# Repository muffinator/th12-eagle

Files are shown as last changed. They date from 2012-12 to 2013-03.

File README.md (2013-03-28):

CAD and Docs for the TH12 sensor
================================

TH12 layout

[Schematic PDF](https://raw.github.com/malvira/th12-eagle/master/docs/th12-revD.pdf)

Tag-Connet Header
-----------------

### Pinout

tag-connect-pinout

Firmware
--------

[Open source firmware](https://github.com/malvira/th-12)

Datasheets
----------
[NCP1400](http://www.onsemi.com/pub_link/Collateral/NCP1400A-D.PDF)[digikey](http://www.digikey.com/product-detail/en/NCP1400ASN33T1G/NCP1400ASN33T1GOSCT-ND/2121294)

License
-------

The TH12 designs are owned by Redwire Consulting, LLC and relased
under the [CERN OPEN HARDWARE LICENCE v1.1](LICENSE.txt)

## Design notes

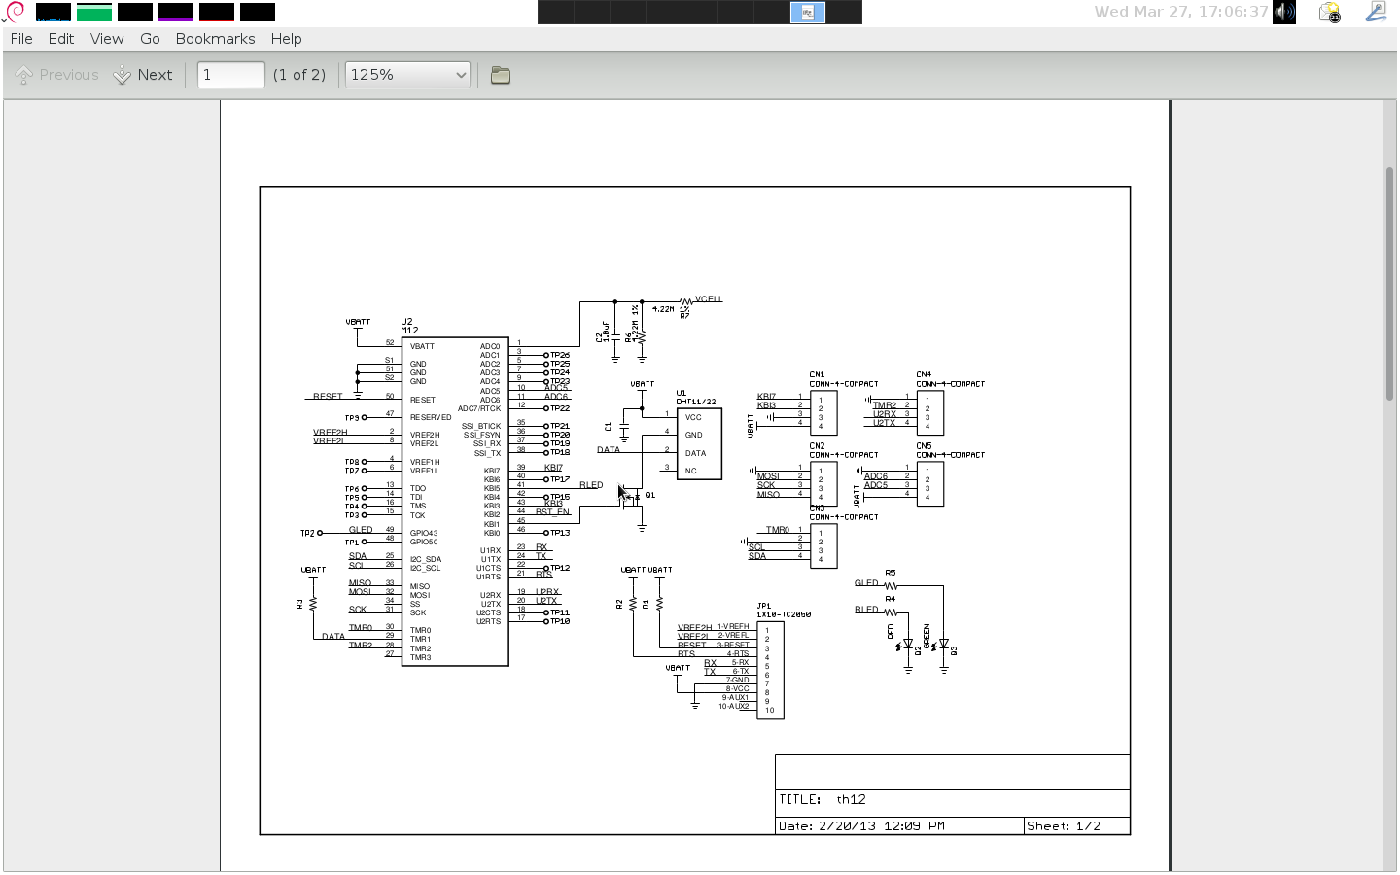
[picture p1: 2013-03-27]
docs/th12-schematic-thumb.png

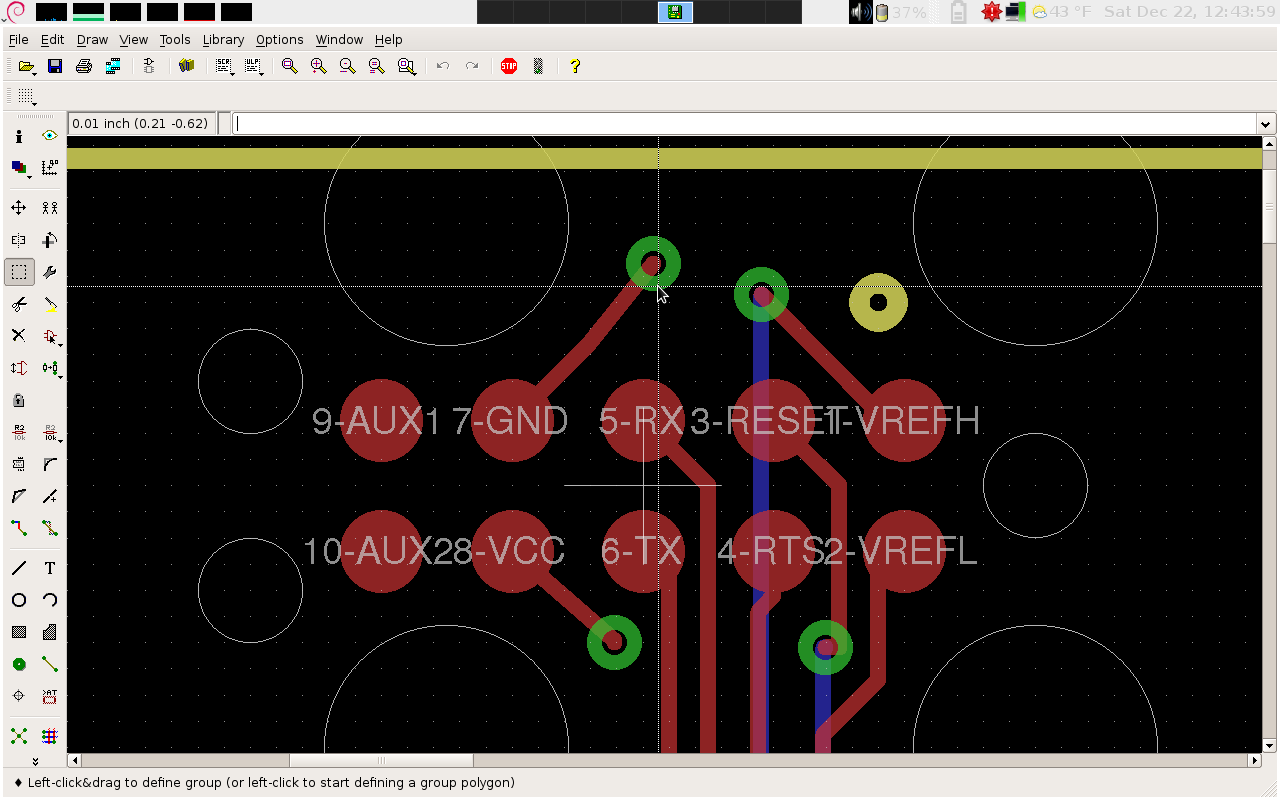
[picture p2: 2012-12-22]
docs/tc-pinout.png

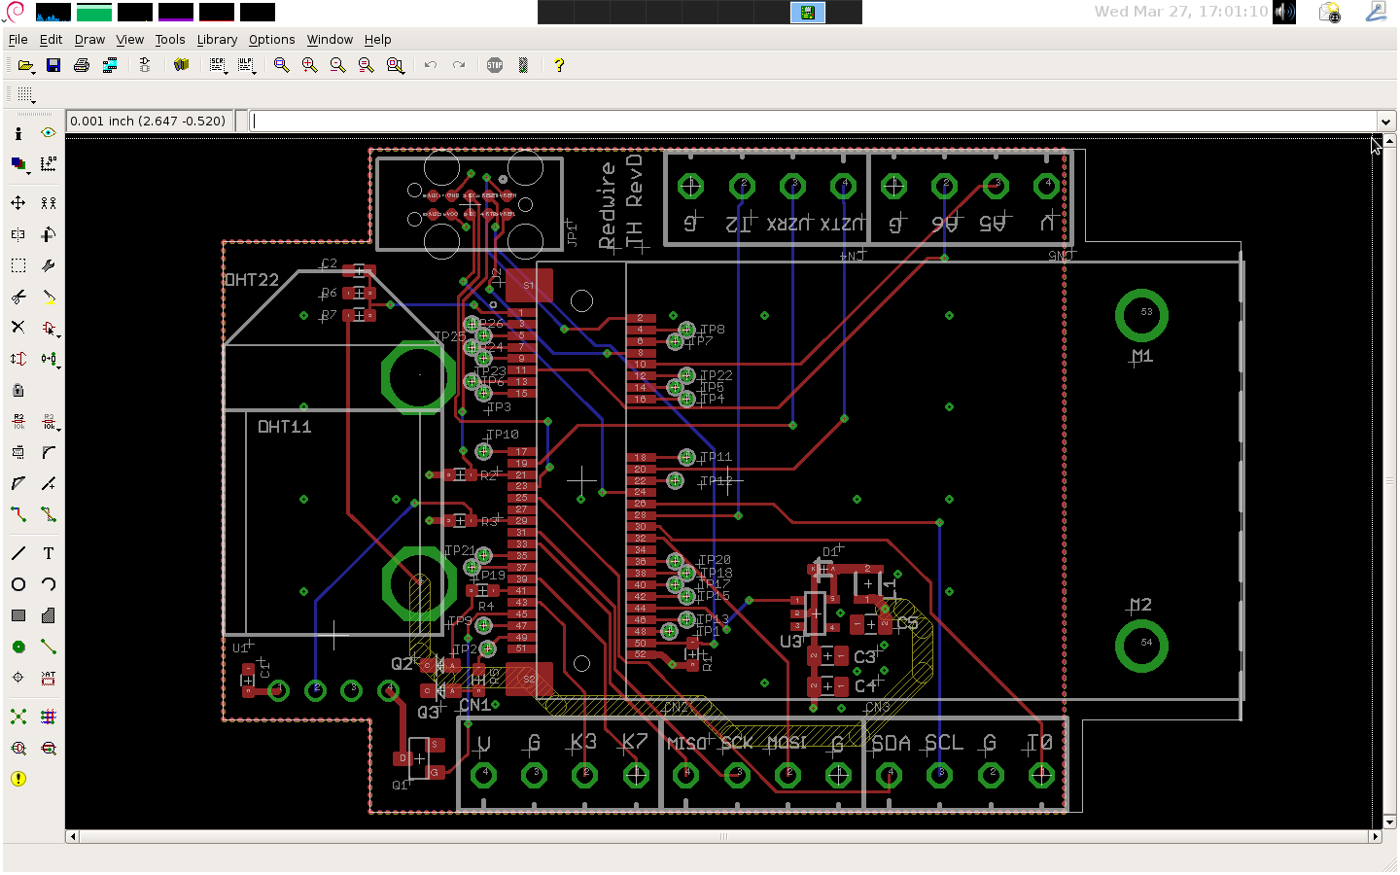
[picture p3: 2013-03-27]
docs/th12-revD-layout.png

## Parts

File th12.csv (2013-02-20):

qty | mfg | partnumber | value | description | designator | footprint | digikey | mouser | notes
2 |  |  | 1u |  | C1 C2 | SMD0603 | 587-1242-1-ND
3 |  |  | 22u |  | C3 C4 C5 | SMD0805 | 445-1422-1-ND
1 |  |  | 22u |  | L1 | SMD1007 | 587-2190-1-ND
1 |  |  |  | DIODE SCHOTTKY 40V 120MA SOD-523 | D1 |  | 568-8118-1-ND
5 |  |  | CONN-4-COMPACT |  | CN1 CN2 CN3 CN4 CN5 | 1X4-3.5MM-COMPACT |  |  | do not place
1 |  |  |  |  | Q1 | SOT23-GSD | 2N7002-FDICT-ND
1 |  |  | RED |  | Q2 | LED0603 | 604-APT1608SRCPRV
1 |  |  | GREEN |  | Q3 | LED0603 | LTST-S270KGKT
2 |  |  | DNP |  | R1 R2 | SMD0603
1 |  |  | 10k |  | R3 | SMD0603 | P10KGCT-ND
1 |  |  | 220 |  | R4 | SMD0603 | P220GCT-ND
1 |  |  | 180 |  | R5 | SMD0603 | P180GCT-ND
2 |  |  | 4.22M 1% |  | R6 R7 | SMD0603 | 541-4.22MHCT-ND
1 |  |  | DHT11/22 |  | U1 | DHT22 |  |  | DHT22/AM2302
1 | JAE Electronics | MM60-52B1-B1-R850 |  | Mini PCIe connector | U2 |  |  | 656-MM60-52B1-B1-R
1 |  |  | NCP1400ASN33T1G |  | U3 | SOT-23-5 | NCP1400ASN33T1GOSCT-ND
2 | JAE Electronics | NT1R3000 | M2 standoff | Mini PCIe standoffs M2 | M1 M2 |  | 670-2481-1-ND

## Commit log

2013-01-25 Rev B release files
    [th12.brd, th12.sch]
2013-01-25 added NCP1400A boost
    [th12.brd, th12.csv, th12.sch]
2013-01-25 fix up silkscreen. This should be ready for release.
    [th12.brd, th12.sch]
2013-01-25 fix miniPCI connector on BOM
    [th12.csv]
2013-01-26 added AD hookup through divider to monitor battery voltage.
    [th12.brd, th12.csv, th12.sch]
2013-01-26 4pcb silk
    [th12.brd]
2013-02-11 add current consumption data regarding an unloaded NCP1400 an various input voltages.
2013-02-11 add shutdown current of 0.8uA to the ncp1400 power sheet
2013-02-15 update values for cell divider
    [th12.brd, th12.csv, th12.sch]
2013-02-20 added filter cap to bat. voltage divider. Bumped to rev D
    [th12.brd, th12.csv, th12.sch]
2013-02-27 add revD schematic
2013-03-27 more pics and links to the schematic in the README
2013-03-27 Add schematic image for the pdf link.
2013-03-27 fix schematic thumbnail in README.
2013-03-27 make just a regular link to the schematic
2013-03-27 really fix the schematic thumb
2013-03-27 link to schematic in README.
